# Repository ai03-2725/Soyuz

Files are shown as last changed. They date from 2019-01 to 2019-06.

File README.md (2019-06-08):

# Soyuz
A single-PCB numpad kit

#### In light of recent claims that I am 100% liable for any of my open source PCBs, I am adding this disclaimer.
#### I provide these PCBs as a reference for designing keyboard PCBs. Using them within your projects will require a will to do research of one's own and to learn the workings of them, potentially fixing issues if they exist.
# I provide these PCBs without liability and without any guarantees regarding functionality, as expressed in the MIT license under which all of these PCBs are licensed.

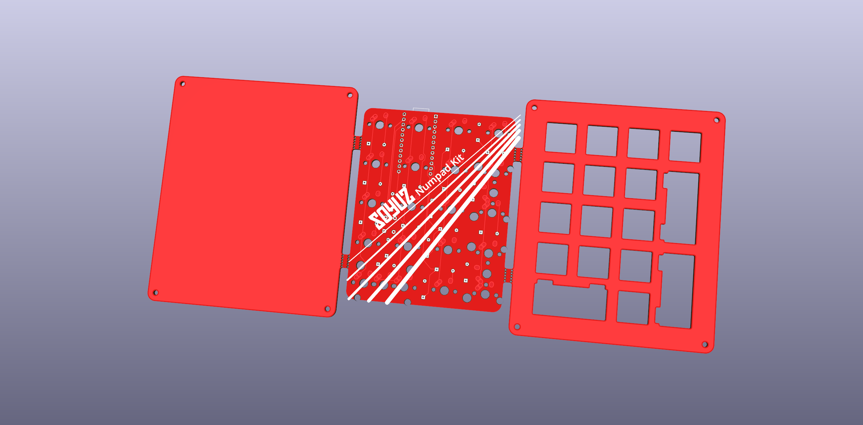
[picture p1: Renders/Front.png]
PCB render


### Build guides
[English](https://github.com/ai03-2725/Soyuz/blob/master/BuildGuide-English.md)
[日本語](https://github.com/ai03-2725/Soyuz/blob/master/BuildGuide-Japanese.md)

### Customizing guide for vendors
[English](https://github.com/ai03-2725/Soyuz/blob/master/VendorGuide-English.md)
[日本語](https://github.com/ai03-2725/Soyuz/blob/master/VendorGuide-Japanese.md)

### Purchasing
If you don't wish to go through the hassle of ordering direct from a fab using gerbers, the board is available for sale at the following:  
* [Spacecat Design](https://spacecat.design/collections/pcbs-cases-kits/products/soyuz-number-pad-kit)
* Yusha Kobo (Available for sale at the physical storefront)

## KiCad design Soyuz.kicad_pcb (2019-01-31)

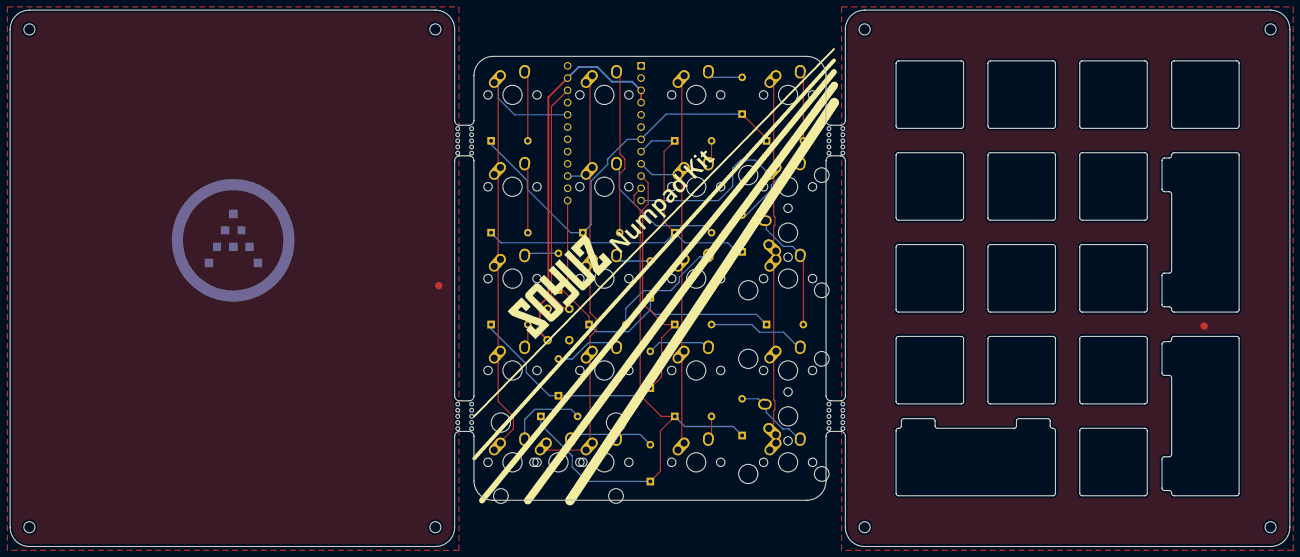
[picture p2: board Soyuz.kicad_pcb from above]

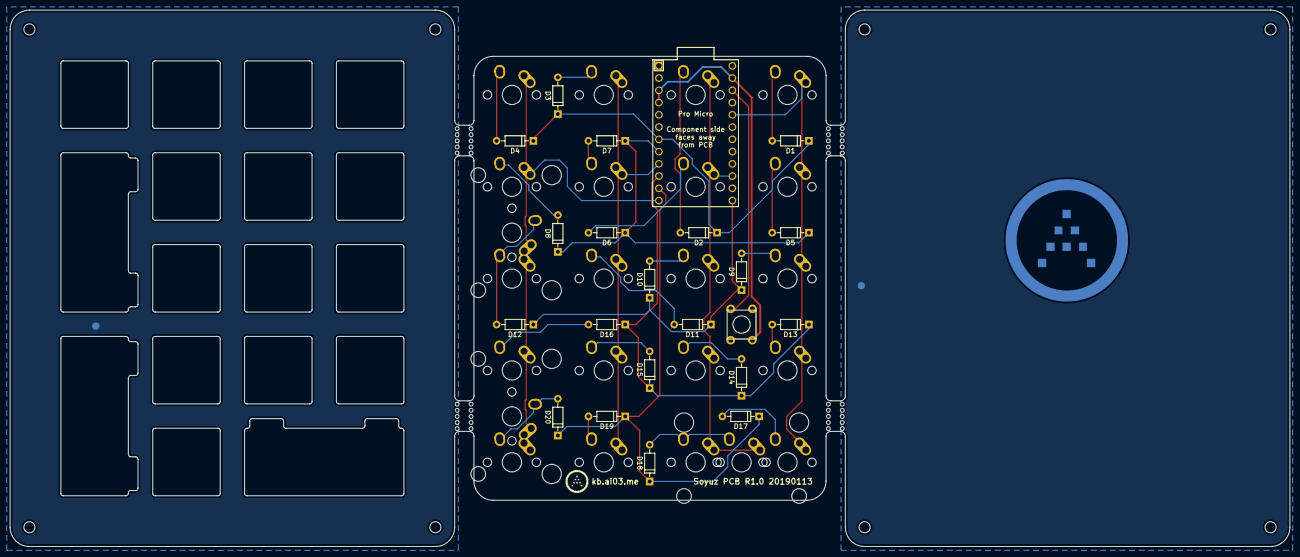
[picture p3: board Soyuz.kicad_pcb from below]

Board: 2 copper layers, 265.4 x 111.2 mm, 54 parts (22 on the bottom side), 31 nets.

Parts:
D1, D2, D3, D4, D5, D6, D7, D8, D9, D10, D11, D12, D13, D14, D15, D16, D17, D18, D19, D20: 1N4148; D_DO-35_SOD27_P7.62mm_Horizontal
MOUSEBITE1, MOUSEBITE2, MOUSEBITE3, MOUSEBITE4, MOUSEBITE5, MOUSEBITE6, MOUSEBITE7, MOUSEBITE8: Mousebites; breakaway-mousebites
MX1, MX2, MX3, MX4, MX5, MX6, MX7, MX8, MX10, MX11, MX12, MX13, MX14, MX15, MX16, MX17, MX19, MX20, MX21, MX22: MX-1U; MX-1U-NoLED
MX9, MX18, MX23: MX-2U; MX-2U-ReversedStabilizers-NoLED
O1: Outline; outline
SW1: SW_Push; PushButton_6x6mm_TH_Pretty
U1: ProMicro; ProMicro-EnforcedTop

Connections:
COL0: MX1.1, MX5.1, MX10.1, MX14.1, MX19.1, U1.20
COL1: MX2.1, MX6.1, MX11.1, MX15.1, MX20.1, MX23.1, U1.15
COL2: MX3.1, MX7.1, MX12.1, MX16.1, MX21.1, U1.9
COL3: MX4.1, MX8.1, MX9.1, MX13.1, MX17.1, MX18.1, MX22.1, U1.12
GND: SW1.2, U1.3, U1.4, U1.23
unnamed: D1.2, MX1.2
unnamed: D2.2, MX2.2
unnamed: D3.2, MX3.2
unnamed: D4.2, MX4.2
unnamed: D5.2, MX5.2
unnamed: D6.2, MX6.2
unnamed: D7.2, MX7.2
unnamed: D8.2, MX8.2
unnamed: D9.2, MX10.2
unnamed: D10.2, MX11.2
unnamed: D11.2, MX12.2
unnamed: D12.2, MX9.2, MX13.2
unnamed: D13.2, MX14.2
unnamed: D14.2, MX15.2
unnamed: D15.2, MX16.2
unnamed: D16.2, MX17.2
unnamed: D17.2, MX19.2
unnamed: D18.2, MX20.2, MX23.2
unnamed: D19.2, MX21.2
unnamed: D20.2, MX18.2, MX22.2
unnamed: SW1.1, U1.22
ROW0: D1.1, D2.1, D3.1, D4.1, U1.7
ROW1: D5.1, D6.1, D7.1, D8.1, U1.8
ROW2: D9.1, D10.1, D11.1, D12.1, U1.13
ROW3: D13.1, D14.1, D15.1, D16.1, U1.10
ROW4: D17.1, D18.1, D19.1, D20.1, U1.11

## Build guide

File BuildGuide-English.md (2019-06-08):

# Soyuz Build Guide

### Bill of Materials

* 1x This PCB (contains top and bottom plates and main PCB)
* 1x Pro Micro, Elite-C, or any clone with identical pinout
* 4x M2 Standoffs, 12~14mm
* 8x M2 screws for the standoffs
* 20x Diodes, 1N4148 
* 17-20x Cherry MX compatible switches, depending on layout
* 0-3x Cherry MX PCB-mount stabilizers, depending on layout
* 1x 6x6mm push button for reset
* 4x Rubber adhesive feet
* Keycaps to cover the numpad
* USB cable  

### Instructions

1. Break the PCB apart into top, bottom, and electrical PCBs carefully. 
2. Solder the diodes onto the PCB.
3. Solder the Pro Micro headers and reset button onto the PCB.
4. Install stabilizers to the PCB if necessary.
5. Clip the corner switches into the top plate, and attach the plate/switch setup onto the PCB.
6. Solder switches onto the PCB.
7. Solder the Pro Micro onto the headers.
8. At this stage, double-check all solder joints and flash firmware.
9. Screw the standoffs on each corner of the top plate.
10. Screw the bottom plate onto the rest.
11. Tack on the rubber feet.
12. Mount keycaps. Enjoy!  

### Building the Firmware

For beginners:
* Use [QMK Configurator](https://config.qmk.fm/#/ai03/soyuz/LAYOUT_ortho_5x4)

For experts:
* [Compile from source](https://github.com/qmk/qmk_firmware/tree/master/keyboards/ai03/soyuz)

### Flashing the firmware

Using [QMK Toolbox](https://github.com/qmk/qmk_toolbox/releases) is recommended.

### Video Guides

SpaceCat Design:  
Video by SpaceCat Design (https://www.youtube.com/watch?v=LFRCjzilOcM)

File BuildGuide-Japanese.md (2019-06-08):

# Soyuz ビルドガイド

### 部品

* 1x PCB（上下のプレートとメインPCBのセット）
* 1x Pro MicroやElite-C等のマイコンボード（ピンアウトが同じなら使えます）
* 4x M2スペーサー、12～14mm
* 8x M2ネジ
* 20x 1N4148ダイオード
* 17-20x Cherry MX互換スイッチ（数はレイアウトによる）
* 0-3x Cherry MX互換PCBスタビライザー（数はレイアウトによる）
* 1x 6x6mmリセットボタン
* 4x ゴム足
* キーキャップ
* USBケーブル  

### 組み立て方

1. PCBをメインPCBとプレート二枚に分解します。
2. ダイオードをPCBへ半田付けします。
3. Pro Micro用のヘッダーとリセットボタンをPCBへ半田付けします。
4. 必要な場合、スタビライザーをPCBに配置します。
5. 四隅のスイッチをスイッチプレートに設置し、PCBと合体させます。
6. スイッチを半田付けします。
7. Pro Microをヘッダーへ半田付けします。
8. この段階で、半田付けにミスがないことを確認し、ファームウエアを書き込みます。
9. スペーサーをスイッチプレートの四隅にネジ止めします。
10. 下プレートをネジ止めします。
11. ゴム足を付けます。
12. キーキャップを載せて完成です。  

### ファームウエアの作成

初心者向け：
* [QMK Configurator](https://config.qmk.fm/#/ai03/soyuz/LAYOUT_ortho_5x4)を使用

玄人向け：
* [ソースからコンパイル](https://github.com/qmk/qmk_firmware/tree/master/keyboards/ai03/soyuz)

### ファームウエアの書き込み

[QMK Toolbox](https://github.com/qmk/qmk_toolbox/releases)を使用することをお勧めします。

### 組み立てビデオ

SpaceCat Design:  
Video by SpaceCat Design (https://www.youtube.com/watch?v=LFRCjzilOcM)

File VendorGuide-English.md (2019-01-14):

# Vendor Guide

If you wish to customize branding, please follow these simple steps to insert your logo on the case.

1. Fork Soyuz on GitHub to create your own copy. Clone onto your PC.
2. Turn your logo into a footprint using bitmap2component, save in locallib.pretty.
3. Place it on the topside of the bottom plate. It is left intentionally blank for this.
4. Alt+3 to render and see if it looks nice.
5. Using the Plot tool, generate the gerbers.

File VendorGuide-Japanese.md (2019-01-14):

# ベンダー用情報

ブランド用に改造したい場合、この手順で簡単にケースにロゴを入れることができます。

1. このレポジトリをフォークして、PCにクローンします。
2. bitmap2componentを使用してロゴをKiCadフットプリントに変換し、locallib.prettyに保存します。
3. 下プレートの上面にロゴを配置します。
4. Alt+3でレンダー画面を開き、見た目を確認します。
5. Plotツールでガーバーファイルを出力します。

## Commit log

2019-01-13 Create empty project
    [Mir.kicad_pcb, Mir.sch]
2019-01-14 Add ground fills
    [Mir.kicad_pcb, Mir.sch]
2019-01-14 Rename project
    [Soyuz.kicad_pcb, Soyuz.sch]
2019-01-14 Create production data
    [Soyuz-B.Cu.gbl, Soyuz-B.Mask.gbs, Soyuz-B.SilkS.gbo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]
2019-01-14 Update spacer dimens
2019-01-31 Update bottom plate artwork
    [Soyuz-B.Cu.gbl, Soyuz-B.Mask.gbs, Soyuz-B.SilkS.gbo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]
2019-01-31 Repair silkscreen
    [Soyuz-B.Cu.gbl, Soyuz-B.Mask.gbs, Soyuz-B.SilkS.gbo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]
